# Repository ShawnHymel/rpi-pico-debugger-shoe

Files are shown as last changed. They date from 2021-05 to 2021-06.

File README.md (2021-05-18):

# RPi Pico Debugger Shoe

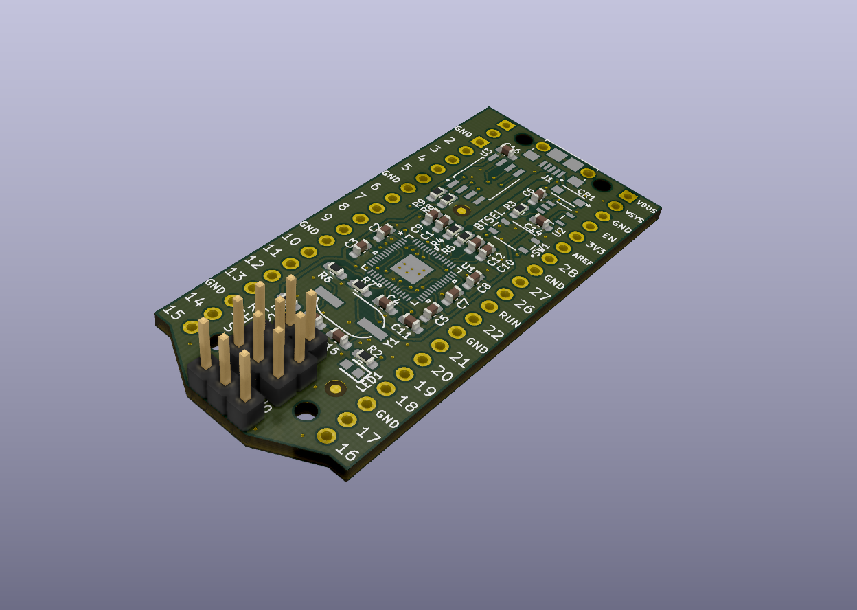
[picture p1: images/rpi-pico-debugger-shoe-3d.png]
Rendered example of RPi Pico Debugger Shoe


Stackable debugger board for the Raspberry Pi Pico. Solder long headers to this debugger board in order to connect the Pico to it. You will also need to connect jumper wires from the bottom CLK, GND, DIO pins to the target pico.

All design files were created using KiCad v5.1.

Feel free to modify this design for your own applciation. This PCB is intended to be a project for testing the layout of the Raspberry Pi RP2040.

Recommended reading:
 * [RP2040 Datasheet](https://datasheets.raspberrypi.org/rp2040/rp2040-datasheet.pdf)
 * [Hardware design with RP2040](https://datasheets.raspberrypi.org/rp2040/hardware-design-with-rp2040.pdf)

## License

Schematic and PCB layout files are licensed under the [CC BY 4.0](https://creativecommons.org/licenses/by/2.0/) license.

THE DESIGN IS PROVIDED "AS IS" AND THE AUTHOR DISCLAIMS ALL WARRANTIES WITH REGARD TO THIS DESIGN INCLUDING ALL IMPLIED WARRANTIES OF MERCHANTABILITY AND FITNESS. IN NO EVENT SHALL THE AUTHOR BE LIABLE FOR ANY SPECIAL, DIRECT, INDIRECT, OR CONSEQUENTIAL DAMAGES OR ANY DAMAGES WHATSOEVER RESULTING FROM LOSS OF USE, DATA OR PROFITS, WHETHER IN AN ACTION OF CONTRACT, NEGLIGENCE OR OTHER TORTIOUS ACTION, ARISING OUT OF OR IN CONNECTION WITH THE USE OR PERFORMANCE OF THIS DESIGN.

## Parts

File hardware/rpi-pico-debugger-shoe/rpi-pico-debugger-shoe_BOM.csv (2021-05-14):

Reference | Quantity | Value | Digi-Key_PN | Digi-Key_Substitute
C13 C15 | 2 | 27pF | 311-1063-1-ND
C6 C10 C12 C14 | 4 | 1uF | 1276-6524-1-ND
C1 C2 C3 C4 C5 C7 C8 C9 C11 C16 | 10 | 0.1uF | 311-1344-1-ND
CR1 | 1 | MBR120VLSFT1G | MBR120VLSFT1GOSCT-ND | SM5817PL-TPMSCT-ND
J1 | 1 | 10118193-0001LF | 609-4616-1-ND
J2 | 1 | Conn_01x02
J8 | 1 | Conn_01x02 | S7035-ND
J3 J6 | 2 | Conn_01x03
J7 | 1 | Conn_01x03 | S7036-ND
J4 | 1 | Conn_01x18 | 1988-1035-ND
J5 | 1 | Conn_01x20 | 1988-1136-ND
JP1 JP2 JP3 | 3 | SolderJumper_2_Bridged
LED1 | 1 | 150060VS75000 | 732-4980-1-ND
R1 R3 R9 | 3 | 10K | 311-10KGRCT-ND
R4 R5 | 2 | 27 | 311-27.0HRCT-ND
R6 | 1 | DNP
R2 R7 R8 | 3 | 1K | 311-1.00KHRCT-ND
SW1 | 1 | PTS810_SJK_250_SMTR_LFS | CKN10503CT-ND
U1 | 1 | RP2040 | TBD
U2 | 1 | AP2112K-3.3TRG1 | AP2112K-3.3TRG1DICT-ND | 893-1075-1-ND
U3 | 1 | W25Q16JVSSIQ | 256-W25Q16JVSSIM-ND | 1092-1222-ND
Y1 | 1 | 12MHz | 535-13415-1-ND

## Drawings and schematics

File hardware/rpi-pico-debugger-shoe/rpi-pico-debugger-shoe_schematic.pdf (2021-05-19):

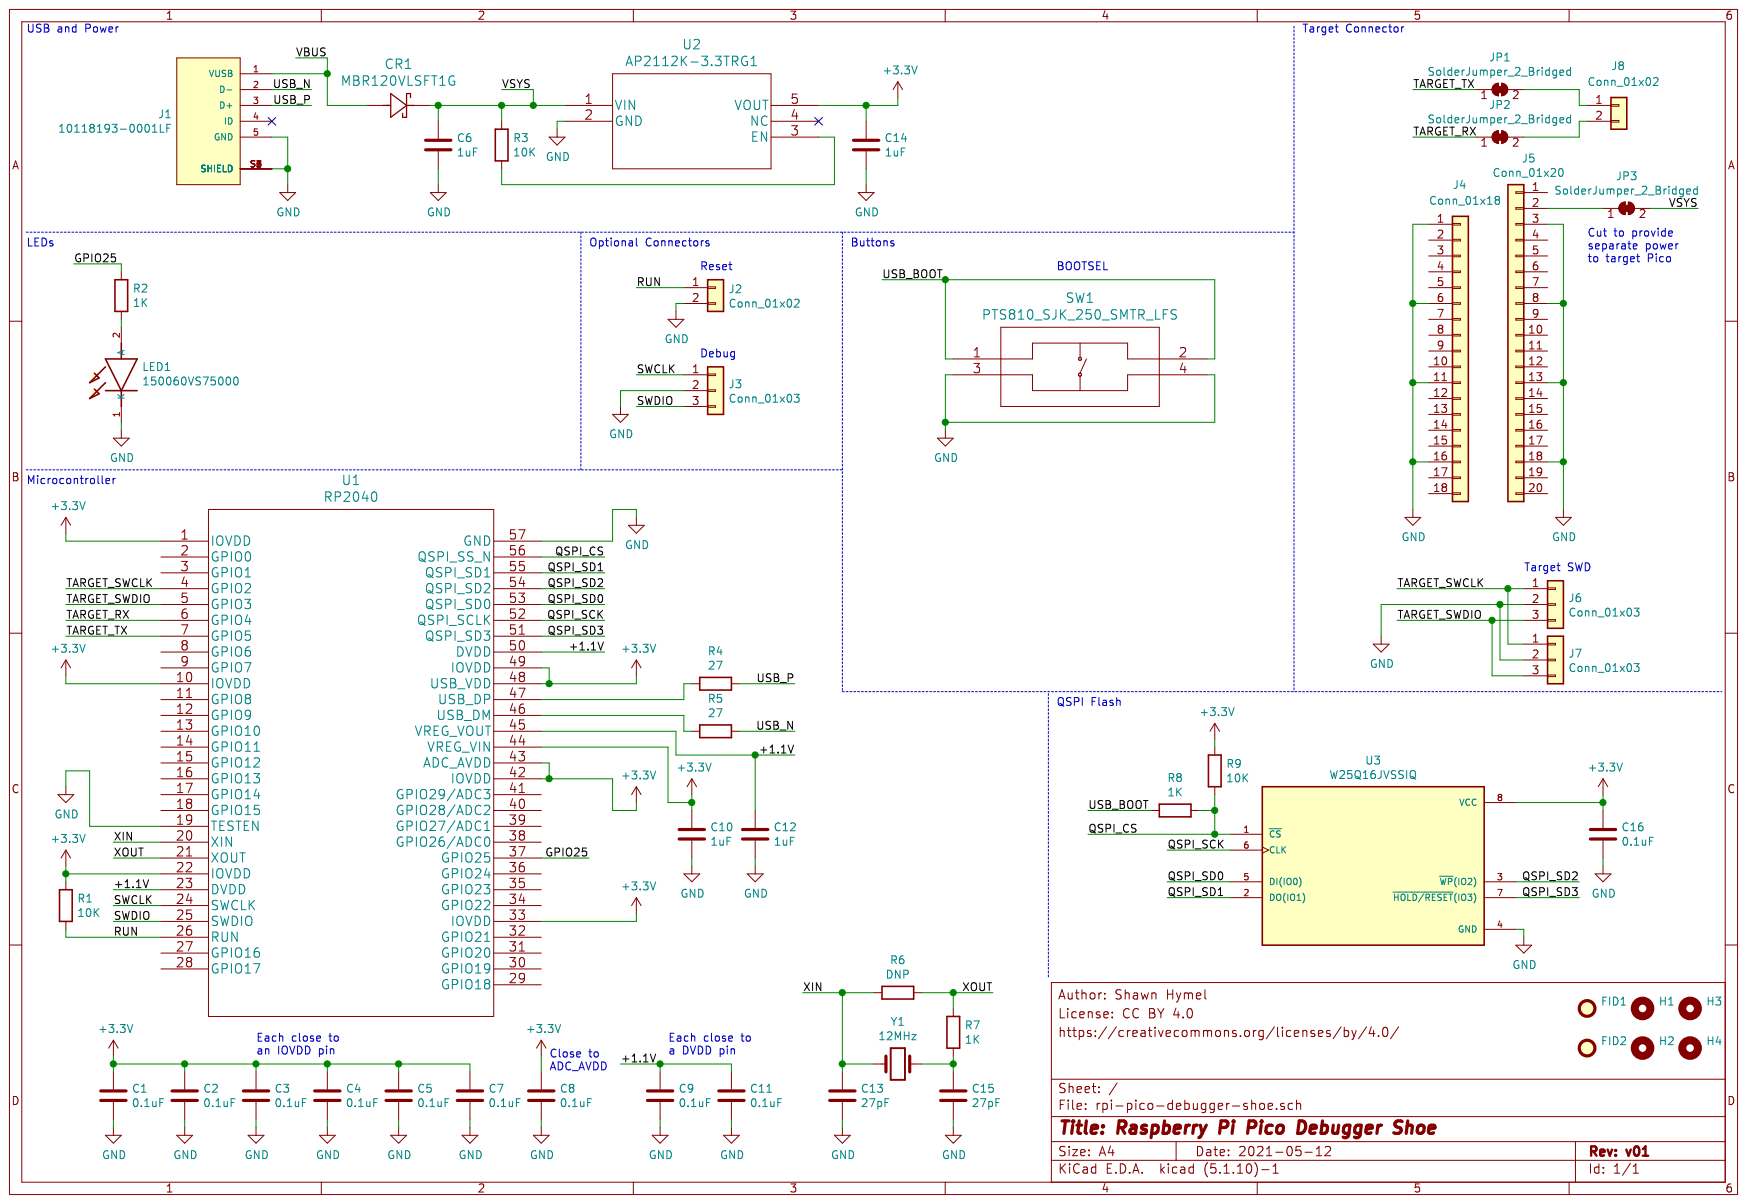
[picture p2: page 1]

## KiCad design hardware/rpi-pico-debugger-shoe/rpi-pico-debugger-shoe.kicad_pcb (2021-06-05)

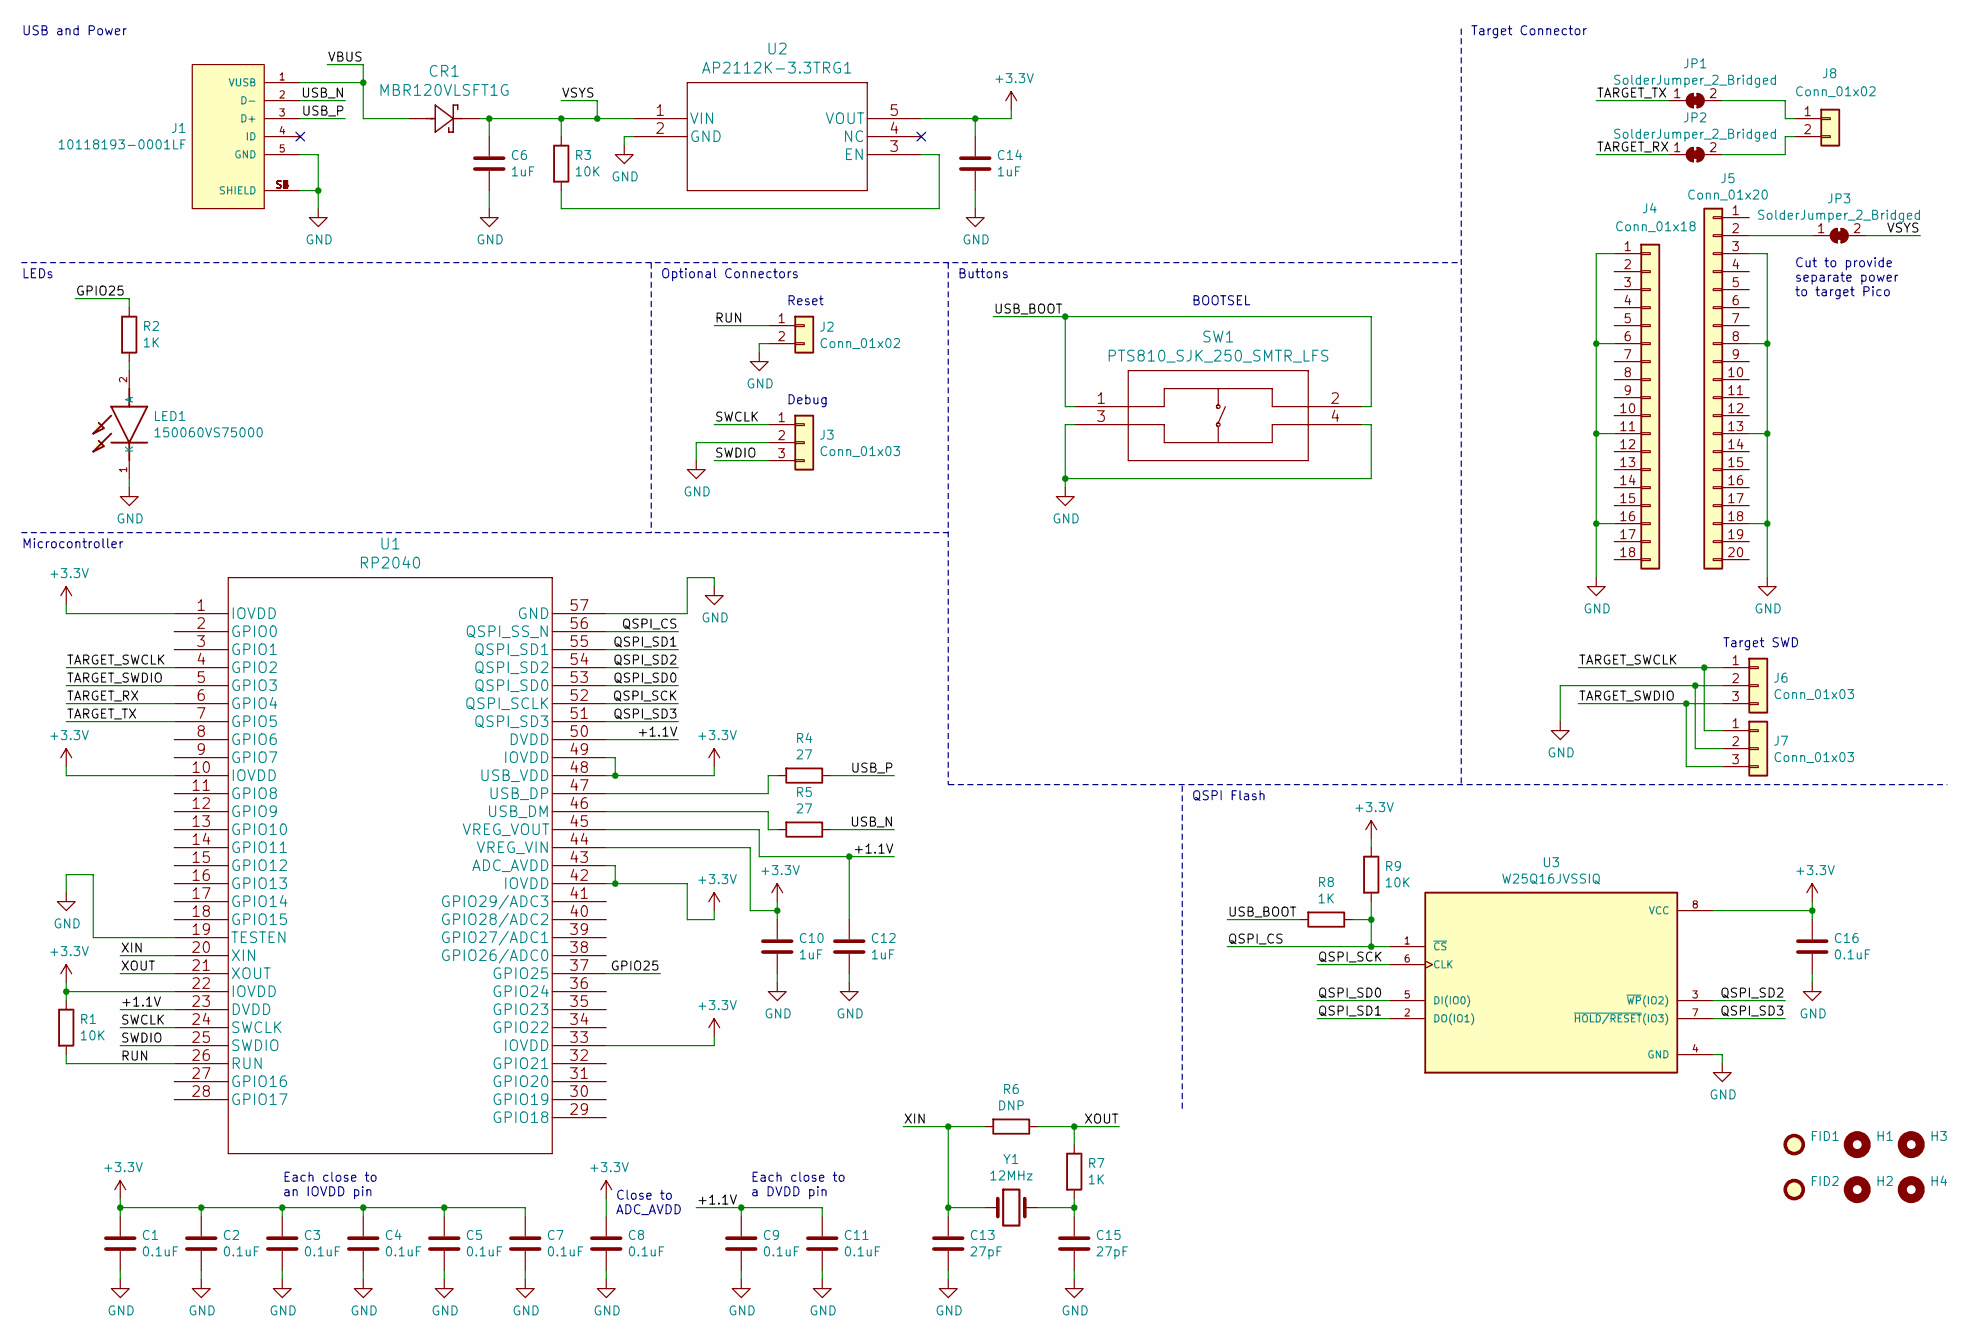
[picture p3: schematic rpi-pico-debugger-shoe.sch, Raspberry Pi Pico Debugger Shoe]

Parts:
C1, C2, C3, C4, C5, C7, C8, C9, C11, C16: 0.1uF; C_0603_1608Metric_Pad1.08x0.95mm_HandSolder; Digi-Key_PN 311-1344-1-ND
C6, C10, C12, C14: 1uF; C_0603_1608Metric_Pad1.08x0.95mm_HandSolder; Digi-Key_PN 1276-6524-1-ND
C13, C15: 27pF; C_0603_1608Metric_Pad1.08x0.95mm_HandSolder; Digi-Key_PN 311-1063-1-ND
CR1: MBR120VLSFT1G; Digi-Key_PN MBR120VLSFT1GOSCT-ND
FID1, FID2: Fiducial; Fiducial_1mm_Mask2mm
H1, H2, H3, H4: MountingHole; MountingHole_2.1mm
J1: 10118193-0001LF; FCI_10118193-0001LF_no-slot; Digi-Key_PN 609-4616-1-ND
J2: Conn_01x02; PinHeader_1x02_P2.54mm_Vertical_no-silk
J3, J6: Conn_01x03; PinHeader_1x03_P2.54mm_Vertical_no-silk
J4: Conn_01x18; PinHeader_1x18_P2.54mm_Vertical_no-silk; Digi-Key_PN 1988-1035-ND
J5: Conn_01x20; PinHeader_1x20_P2.54mm_Vertical_no-silk; Digi-Key_PN 1988-1136-ND
J7: Conn_01x03; PinHeader_1x03_P2.54mm_Vertical_no-silk; Digi-Key_PN S7036-ND
J8: Conn_01x02; PinHeader_1x02_P2.54mm_Vertical_no-silk; Digi-Key_PN S7035-ND
JP1, JP2, JP3: SolderJumper_2_Bridged; SolderJumper-2_P1.3mm_Bridged_RoundedPad1.0x1.5mm
LED1: 150060VS75000; LEDC1608X80N; MOUSER_PART_NUMBER 710-150060VS75000
R1, R3, R9: 10K; R_0603_1608Metric_Pad0.98x0.95mm_HandSolder; Digi-Key_PN 311-10KGRCT-ND
R2, R7, R8: 1K; R_0603_1608Metric_Pad0.98x0.95mm_HandSolder; Digi-Key_PN 311-1.00KHRCT-ND
R4, R5: 27; R_0603_1608Metric_Pad0.98x0.95mm_HandSolder; Digi-Key_PN 311-27.0HRCT-ND
R6: DNP; R_0603_1608Metric_Pad0.98x0.95mm_HandSolder
SW1: PTS810_SJK_250_SMTR_LFS; PTS810 SJK 250 SMTR LFS; Digi-Key_PN CKN10503CT-ND
U1: RP2040; Digi-Key_PN TBD
U2: AP2112K-3.3TRG1; Digi-Key_PN AP2112K-3.3TRG1DICT-ND
U3: W25Q16JVSSIQ; SOIC127P790X216-8N; Digi-Key_PN 256-W25Q16JVSSIM-ND
Y1: 12MHz; ABLS7M2-16.000MHZ-D-2Y-T; Digi-Key_PN 535-13415-1-ND

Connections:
+3V3: C1.1, C2.1, C3.1, C4.1, C5.1, C7.1, C8.1, C10.1, C14.1, C16.1, R1.1, R9.1, U1.1 (IOVDD), U1.10 (IOVDD), U1.22 (IOVDD), U1.33 (IOVDD), U1.42 (IOVDD), U1.43 (ADC_AVDD), U1.44 (VREG_VIN), U1.48 (USB_VDD), U1.49 (IOVDD), U2.5 (VOUT), U3.8 (VCC)
/+1.1V: C9.1, C11.1, C12.1, U1.23 (DVDD), U1.45 (VREG_VOUT), U1.50 (DVDD)
/GPIO25: R2.1, U1.37 (GPIO25)
/QSPI_CS: R8.1, R9.2, U1.56 (QSPI_SS_N), U3.1 (~CS)
/QSPI_SCK: U1.52 (QSPI_SCLK), U3.6 (CLK)
/QSPI_SD0: U1.53 (QSPI_SD0), U3.5 (DI(IO0))
/QSPI_SD1: U1.55 (QSPI_SD1), U3.2 (DO(IO1))
/QSPI_SD2: U1.54 (QSPI_SD2), U3.3 (~WP~(IO2))
/QSPI_SD3: U1.51 (QSPI_SD3), U3.7 (~HOLD/RESET~(IO3))
/RUN: J2.1, R1.2, U1.26 (RUN)
/SWCLK: J3.1, U1.24 (SWCLK)
/SWDIO: J3.3, U1.25 (SWDIO)
/TARGET_RX: JP2.1 (A), U1.6 (GPIO4)
/TARGET_SWCLK: J6.1, J7.1, U1.4 (GPIO2)
/TARGET_SWDIO: J6.3, J7.3, U1.5 (GPIO3)
/TARGET_TX: JP1.1 (A), U1.7 (GPIO5)
/USB_BOOT: R8.2, SW1.1, SW1.2
/USB_N: J1.2 (D-), R5.1
/USB_P: J1.3 (D+), R4.1
/VBUS: CR1.2, J1.1 (VUSB)
/VSYS: C6.1, CR1.1, JP3.2 (B), R3.1, U2.1 (VIN)
/XIN: C13.1, R6.2, U1.20 (XIN), Y1.1
/XOUT: R6.1, R7.1, U1.21 (XOUT)
GND: C1.2, C2.2, C3.2, C4.2, C5.2, C6.2, C7.2, C8.2, C9.2, C10.2, C11.2, C12.2, C13.2, C14.2, C15.2, C16.2, J1.5 (GND), J1.S1 (SHIELD), J1.S2 (SHIELD), J1.S3 (SHIELD), J1.S4 (SHIELD), J1.S5 (SHIELD), J1.S6 (SHIELD), J2.2, J3.2, J4.1, J4.6, J4.11, J4.16, J5.3, J5.8, J5.13, J5.18, J6.2, J7.2, LED1.1 (K), SW1.3, SW1.4, U1.19 (TESTEN), U1.57 (GND), U2.2 (GND), U3.4 (GND)
unnamed: C15.1, R7.2, Y1.2
unnamed: J5.2, JP3.1 (A)
unnamed: J8.1, JP1.2 (B)
unnamed: J8.2, JP2.2 (B)
unnamed: LED1.2 (A), R2.2
unnamed: R3.2, U2.3 (EN)
unnamed: R4.2, U1.47 (USB_DP)
unnamed: R5.2, U1.46 (USB_DM)

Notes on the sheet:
Close to ADC_AVDD
Each close to an IOVDD pin
Each close to a DVDD pin
BOOTSEL
Debug
Reset
Target SWD
Buttons
USB and Power
LEDs
Optional Connectors
Target Connector
Microcontroller
QSPI Flash
Cut to provide separate power to target Pico

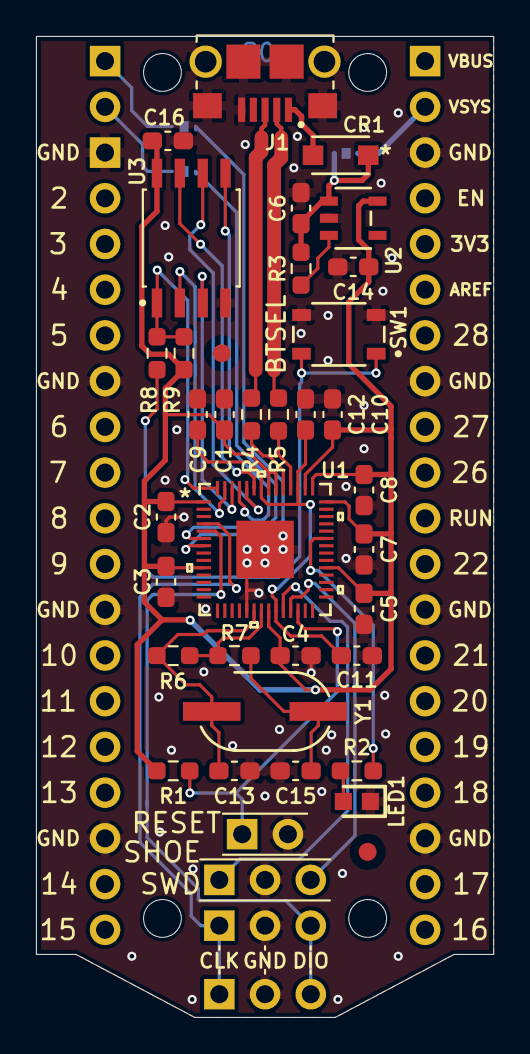
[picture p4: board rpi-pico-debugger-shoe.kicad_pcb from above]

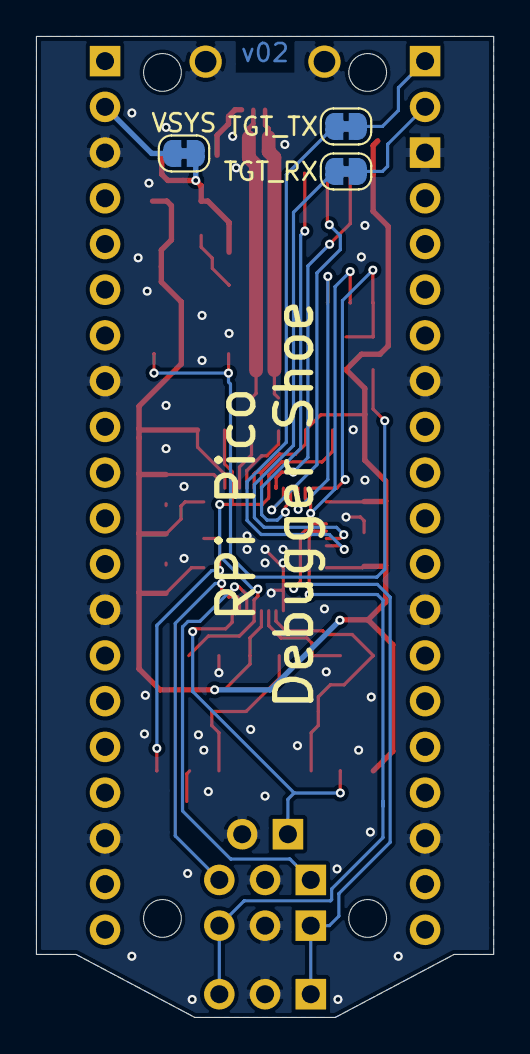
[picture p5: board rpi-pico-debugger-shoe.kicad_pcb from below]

Board: 2 copper layers, 25.4 x 54.5 mm, 49 parts (3 on the bottom side), 32 nets.

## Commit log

2021-05-12 Added some parts from third-party libraries
    [rpi-pico-debugger-shoe.kicad_pcb, rpi-pico-debugger-shoe.sch]
2021-05-14 Finished schematic and BOM for v01
    [rpi-pico-debugger-shoe.kicad_pcb, rpi-pico-debugger-shoe.sch]
2021-05-14 Added BOM file
    [rpi-pico-debugger-shoe_BOM.csv]
2021-05-15 Did done some layouts
    [rpi-pico-debugger-shoe.kicad_pcb, rpi-pico-debugger-shoe.sch]
2021-05-16 Finished layout for v01
    [rpi-pico-debugger-shoe-B_Cu.gbl, rpi-pico-debugger-shoe-B_Mask.gbs, rpi-pico-debugger-shoe-B_Paste.gbp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]
2021-05-18 Added image of shoe.
    [rpi-pico-debugger-shoe.kicad_pcb]
2021-05-19 Added PDF schematic
2021-06-05 Swapped R8 and R9 silk because I messed that up in v01.
    [rpi-pico-debugger-shoe.kicad_pcb, rpi-pico-debugger-shoe.sch]

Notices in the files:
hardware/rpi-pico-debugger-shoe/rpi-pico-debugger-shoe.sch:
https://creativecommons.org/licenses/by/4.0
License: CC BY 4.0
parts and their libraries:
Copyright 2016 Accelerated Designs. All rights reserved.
